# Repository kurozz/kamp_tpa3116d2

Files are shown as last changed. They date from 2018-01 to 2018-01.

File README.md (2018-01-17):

# KAmp

Audio amplifier based on the evaluation module from Texas Instruments.

It should be able to drive 2 speakers at a max of 50W each or a single speaker at a max of 100W (PBTL). Minimal changes are need to change to PBTL.

Multiple devices can be chained together using the Sync connectors. One device should be made Master while the others should operate as Slave devices.

This is not finished and not tested. Will keep updating if I feel like it.

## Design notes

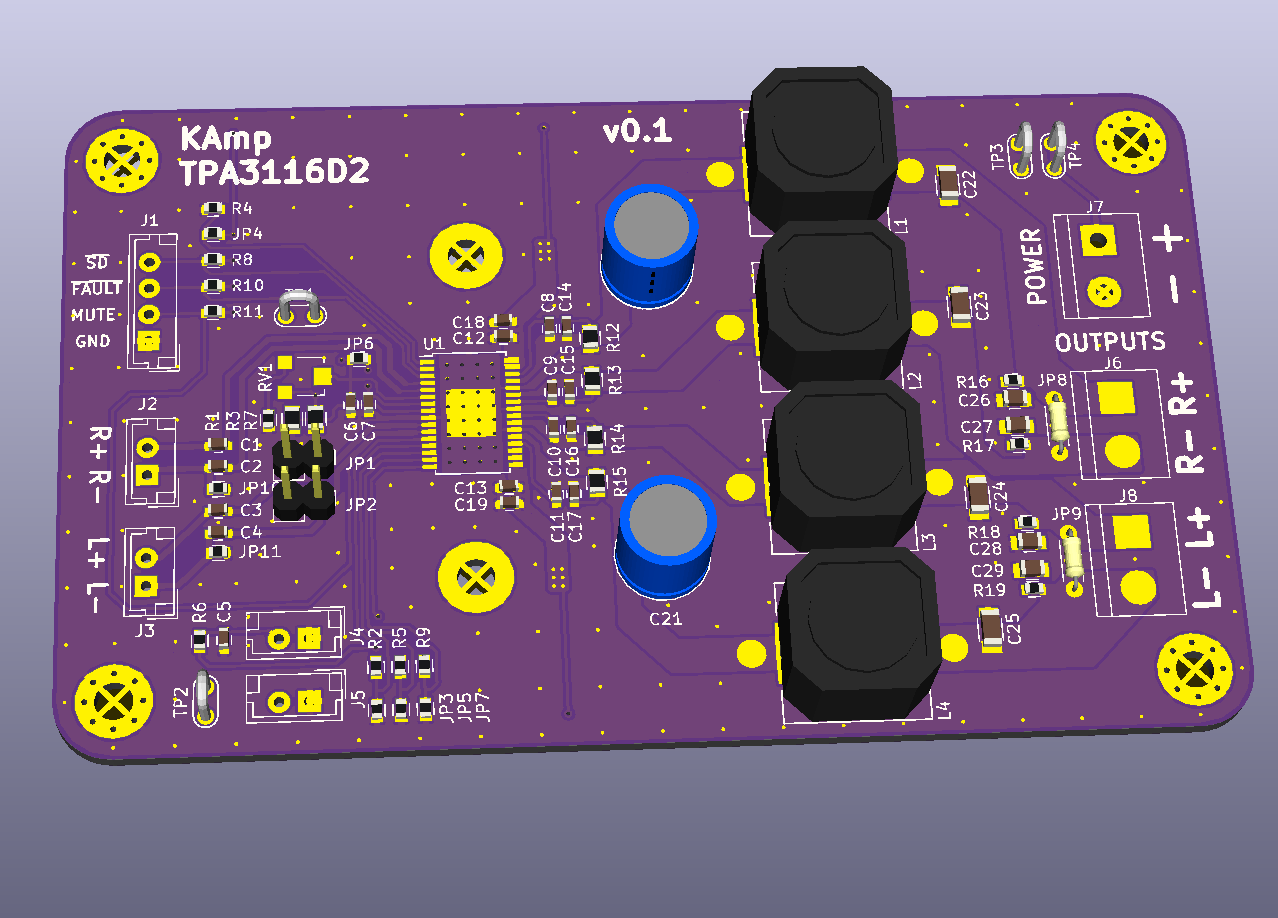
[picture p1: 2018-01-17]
KAmp_TPA3116D2/img/KAmp_TPA3116D2.png

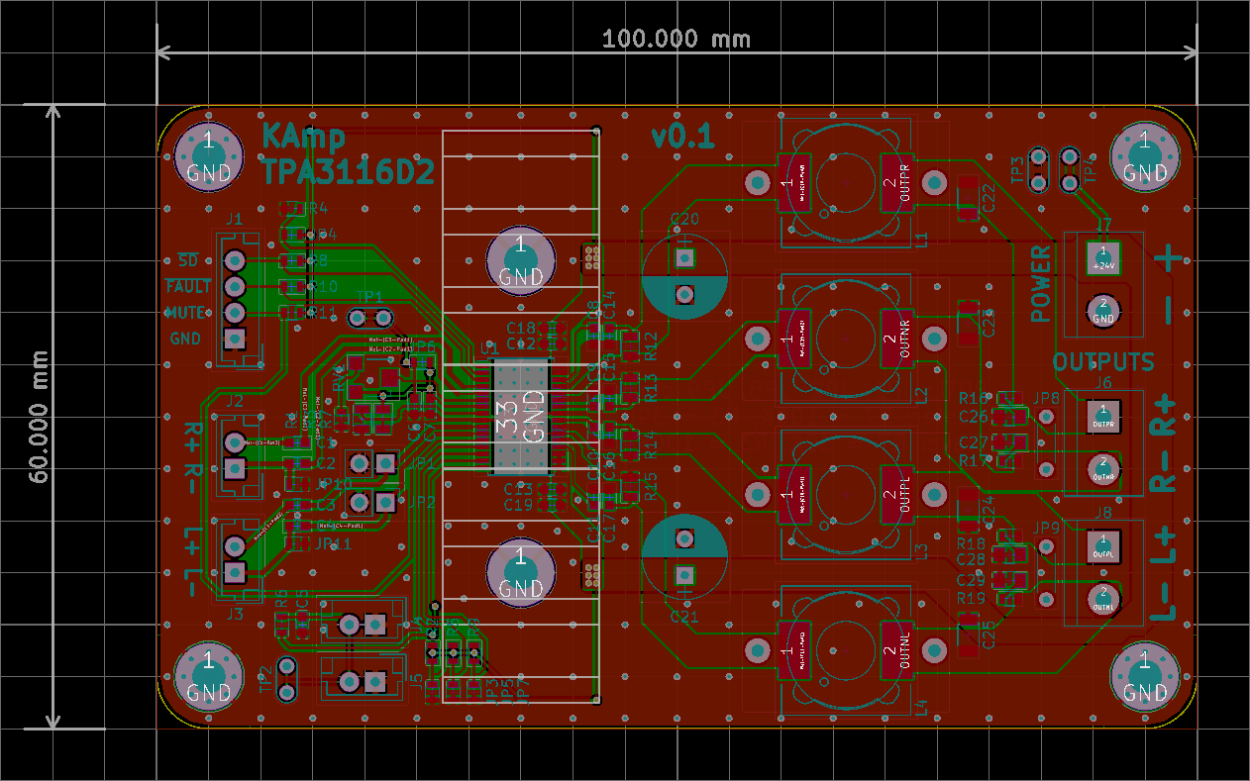
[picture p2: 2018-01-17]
KAmp_TPA3116D2/img/kamp_board.png

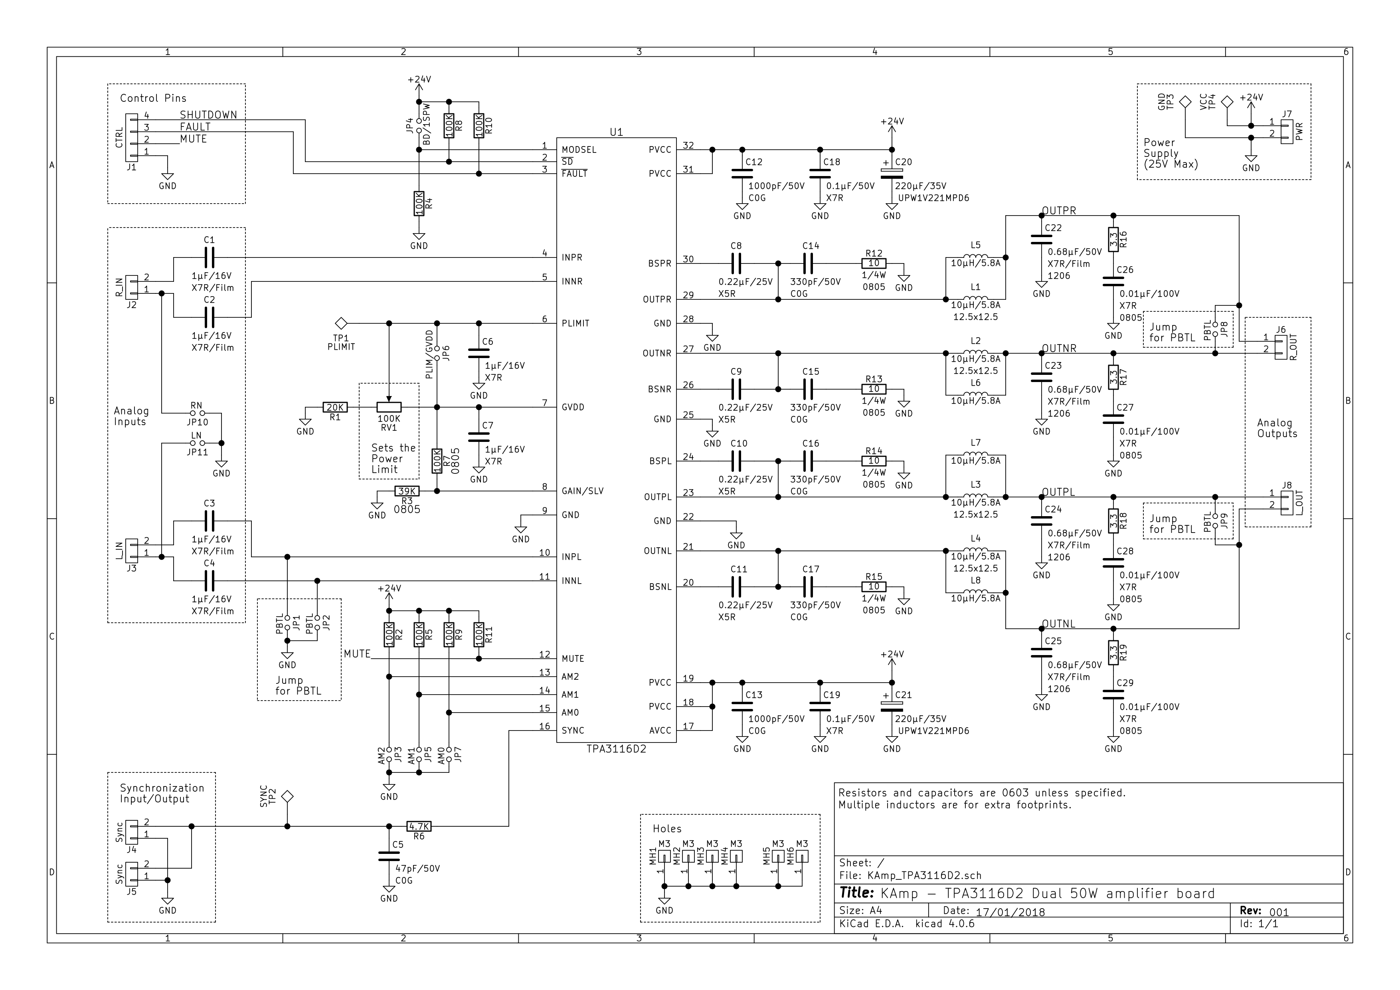
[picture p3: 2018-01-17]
KAmp_TPA3116D2/img/KAmp_TPA3116D2.sch.png

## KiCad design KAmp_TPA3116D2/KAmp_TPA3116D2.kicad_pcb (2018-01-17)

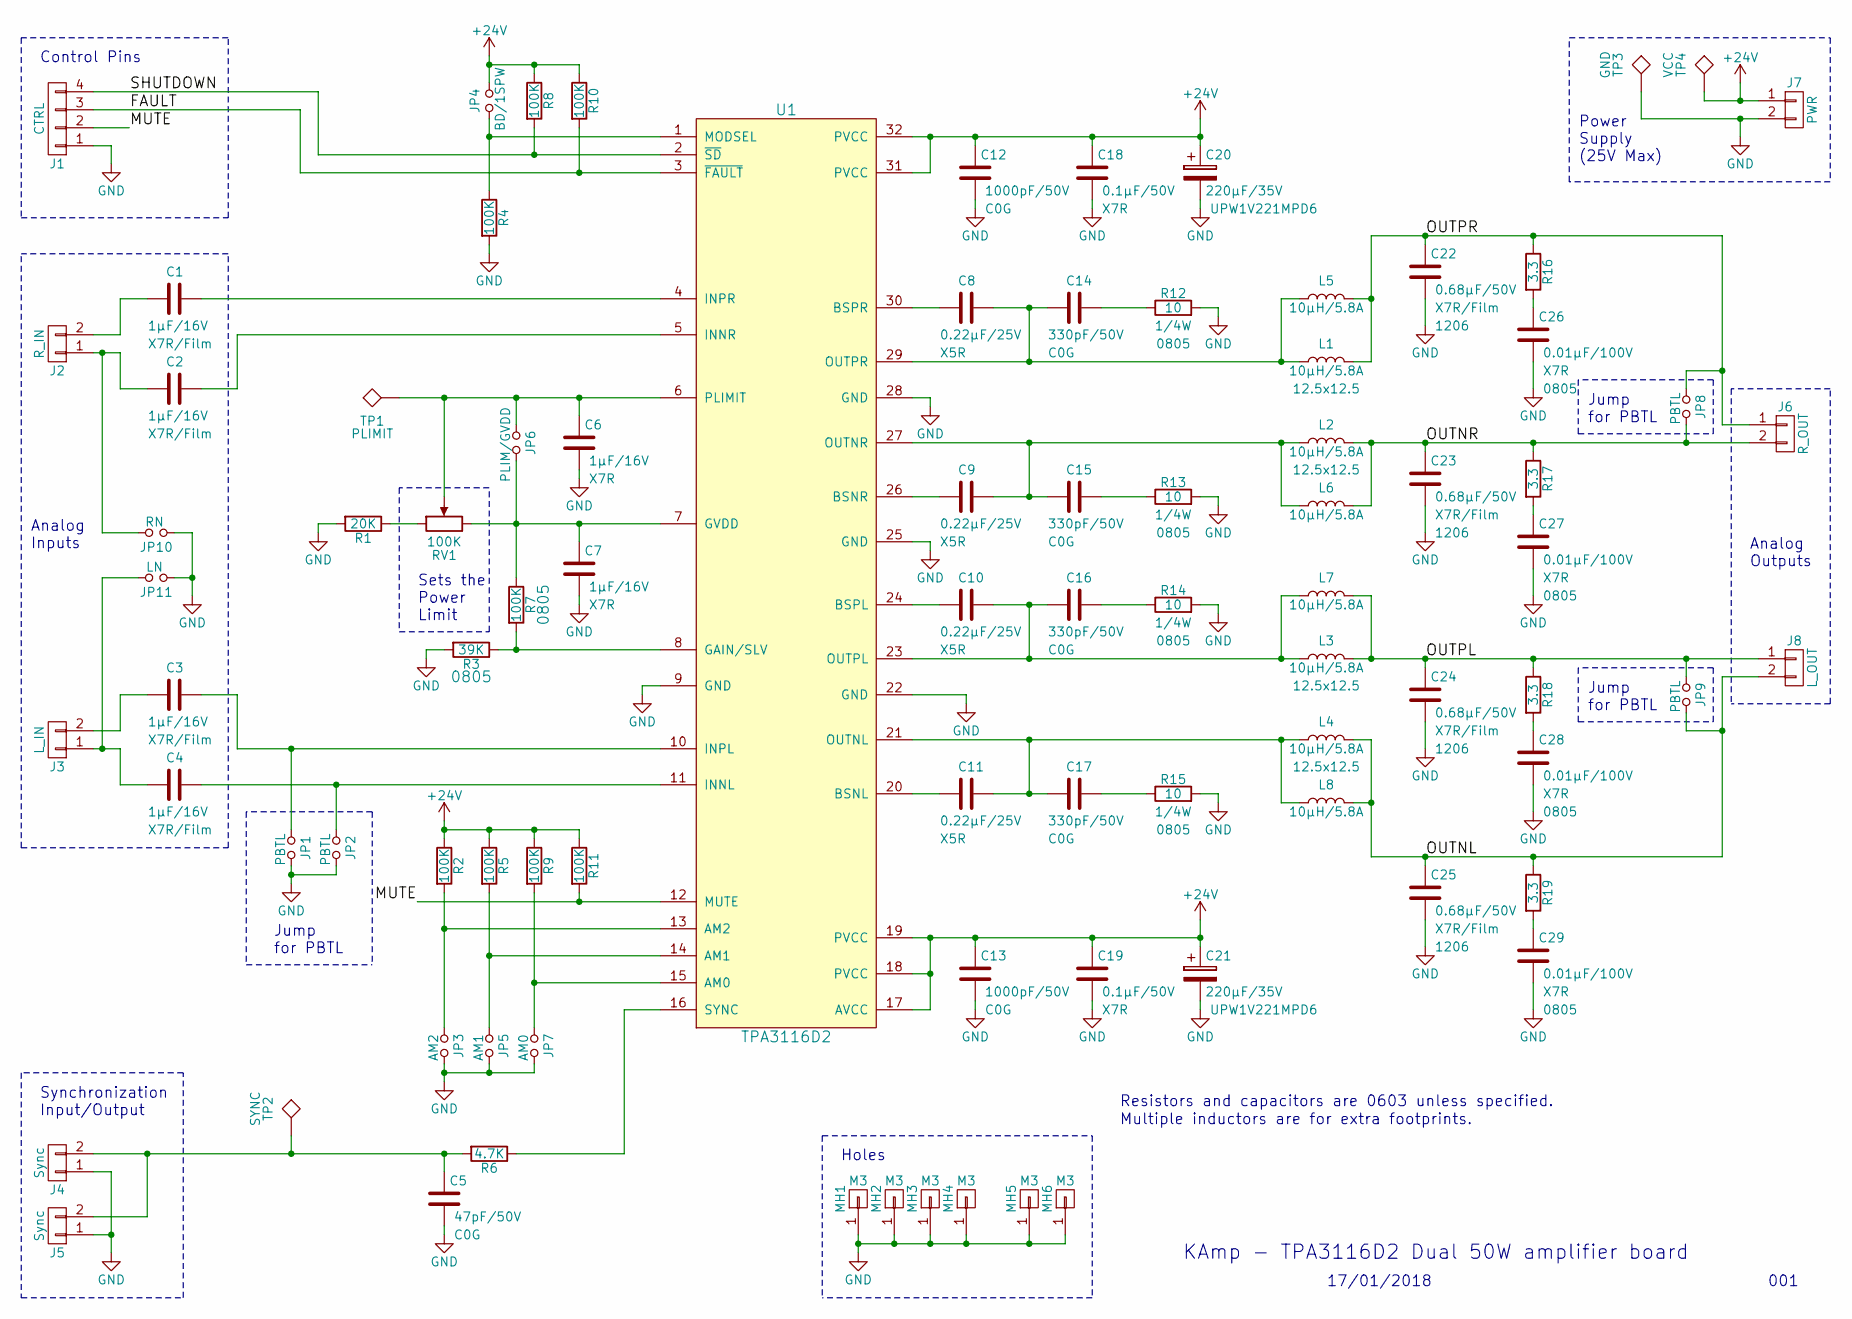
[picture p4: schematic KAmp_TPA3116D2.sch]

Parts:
C1, C2, C3, C4: 1µF/16V; C_0603; Rating X7R/Film
C5: 47pF/50V; C_0603; Rating C0G
C6, C7: 1µF/16V; C_0603; Rating X7R
C8, C9, C10, C11: 0.22µF/25V; C_0603; Rating X5R
C12, C13: 1000pF/50V; C_0603; Rating C0G
C14, C15, C16, C17: 330pF/50V; C_0603; Rating C0G
C18, C19: 0.1µF/50V; C_0603; Rating X7R
C20, C21: 220µF/35V; CP_Radial_D8.0mm_P3.50mm
C22, C23, C24, C25: 0.68µF/50V; C_1206; Rating X7R/Film
C26, C27, C28, C29: 0.01µF/100V; C_0805; Rating X7R
J1: CTRL; JST_EH_B04B-EH-A_04x2.50mm_Straight
J2: R_IN; JST_EH_B02B-EH-A_02x2.50mm_Straight
J3: L_IN; JST_EH_B02B-EH-A_02x2.50mm_Straight
J4, J5: Sync; JST_EH_B02B-EH-A_02x2.50mm_Straight
J6: R_OUT; TerminalBlock_bornier-2_P5.08mm
J7: PWR; TerminalBlock_bornier-2_P5.08mm
J8: L_OUT; TerminalBlock_bornier-2_P5.08mm
JP1, JP2: PBTL; Pin_Header_Straight_1x02_Pitch2.54mm
JP3: AM2; R_0603
JP4: BD/1SPW; R_0603
JP5: AM1; R_0603
JP6: PLIM/GVDD; R_0603
JP7: AM0; R_0603
JP8, JP9: PBTL; R_Axial_DIN0204_L3.6mm_D1.6mm_P5.08mm_Horizontal
JP10: RN; R_0603
JP11: LN; R_0603
L1, L2, L3, L4: 10µH/5.8A; Choke_SMD_12x12mm_h8mm
L5, L6, L7, L8: 10µH/5.8A; L_Toroid_Horizontal_D11.2mm_P17.00mm_Diameter12-5mm_Amidon-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
MH1, MH2, MH3, MH4: M3; MountingHole_3.2mm_M3_Pad_Via
MH5, MH6: M3; MountingHole_3.2mm_M3_Pad
R1: 20K; R_0603
R2, R4, R5, R8, R9, R10, R11: 100K; R_0603
R3: 39K; R_0805
R6: 4.7K; R_0603
R7: 100K; R_0805
R12, R13, R14, R15: 10; R_0805
R16, R17, R18, R19: 3.3; R_0603
RV1: 100K; Potentiometer_Trimmer-EVM3E
TP1: PLIMIT; Test_Point
TP2: SYNC; Test_Point
TP3: GND; Test_Point
TP4: VCC; Test_Point
U1: TPA3116D2; HTSSOP-32_6.1x11mm_Pitch0.65mm_ThermalPad

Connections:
+24V: C12.1, C13.1, C18.1, C19.1, C20.1, C21.1, J7.1, JP4.2, R2.1, R5.1, R8.1, R9.1, R10.1, R11.1, TP4.1, U1.17 (AVCC), U1.18 (PVCC), U1.19 (PVCC), U1.31 (PVCC), U1.32 (PVCC)
/FAULT: J1.3, R10.2, U1.3 (~FAULT)
/MUTE: J1.2, R11.2, U1.12 (MUTE)
/OUTNL: C25.1, J8.2, JP9.2, L4.2, L8.2, R19.1
/OUTNR: C23.1, J6.2, JP8.2, L2.2, L6.2, R17.1
/OUTPL: C24.1, J8.1, JP9.1, L3.2, L7.2, R18.1
/OUTPR: C22.1, J6.1, JP8.1, L1.2, L5.2, R16.1
/SHUTDOWN: J1.4, R8.2, U1.2 (~SD)
GND: C5.2, C6.2, C7.2, C12.2, C13.2, C18.2, C19.2, C20.2, C21.2, C22.2, C23.2, C24.2, C25.2, C26.2, C27.2, C28.2, C29.2, J1.1, J4.1, J5.1, J7.2, JP1.2, JP2.2, JP3.2, JP5.2, JP7.2, JP10.1, JP11.1, MH1.1, MH2.1, MH3.1, MH4.1, MH5.1, MH6.1, R1.2, R3.2, R4.2, R12.2, R13.2, R14.2, R15.2, TP3.1, U1.9 (GND), U1.22 (GND), U1.25 (GND), U1.28 (GND), U1.33 (GND)
unnamed: C1.1, U1.4 (INPR)
unnamed: C1.2, J2.2
unnamed: C2.1, U1.5 (INNR)
unnamed: C2.2, J2.1, JP10.2
unnamed: C3.1, JP1.1, U1.10 (INPL)
unnamed: C3.2, J3.2
unnamed: C4.1, JP2.1, U1.11 (INNL)
unnamed: C4.2, J3.1, JP11.2
unnamed: C5.1, J4.2, J5.2, R6.2, TP2.1
unnamed: C6.1, JP6.1, RV1.2, TP1.1, U1.6 (PLIMIT)
unnamed: C7.1, JP6.2, R7.1, RV1.3, U1.7 (GVDD)
unnamed: C8.2, U1.30 (BSPR)
unnamed: C9.2, U1.26 (BSNR)
unnamed: C10.1, C16.2, L3.1, L7.1, U1.23 (OUTPL)
unnamed: C10.2, U1.24 (BSPL)
unnamed: C11.1, C17.2, L4.1, L8.1, U1.21 (OUTNL)
unnamed: C11.2, U1.20 (BSNL)
unnamed: C14.1, R12.1
unnamed: C8.1, C14.2, L1.1, L5.1, U1.29 (OUTPR)
unnamed: C15.1, R13.1
unnamed: C9.1, C15.2, L2.1, L6.1, U1.27 (OUTNR)
unnamed: C16.1, R14.1
unnamed: C17.1, R15.1
unnamed: C26.1, R16.2
unnamed: C27.1, R17.2
unnamed: C28.1, R18.2
unnamed: C29.1, R19.2
unnamed: JP3.1, R2.2, U1.13 (AM2)
unnamed: JP4.1, R4.1, U1.1 (MODSEL)
unnamed: JP5.1, R5.2, U1.14 (AM1)
unnamed: JP7.1, R9.2, U1.15 (AM0)
unnamed: R1.1, RV1.1
unnamed: R3.1, R7.2, U1.8 (GAIN/SLV)
unnamed: R6.1, U1.16 (SYNC)

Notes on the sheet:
Synchronization Input/Output
Analog Inputs
Jump for PBTL
Control Pins
Power Supply (25V Max)
Analog Outputs
Sets the Power Limit
Holes
KAmp - TPA3116D2 Dual 50W amplifier board
17/01/2018
001
Resistors and capacitors are 0603 unless specified.
Multiple inductors are for extra footprints.

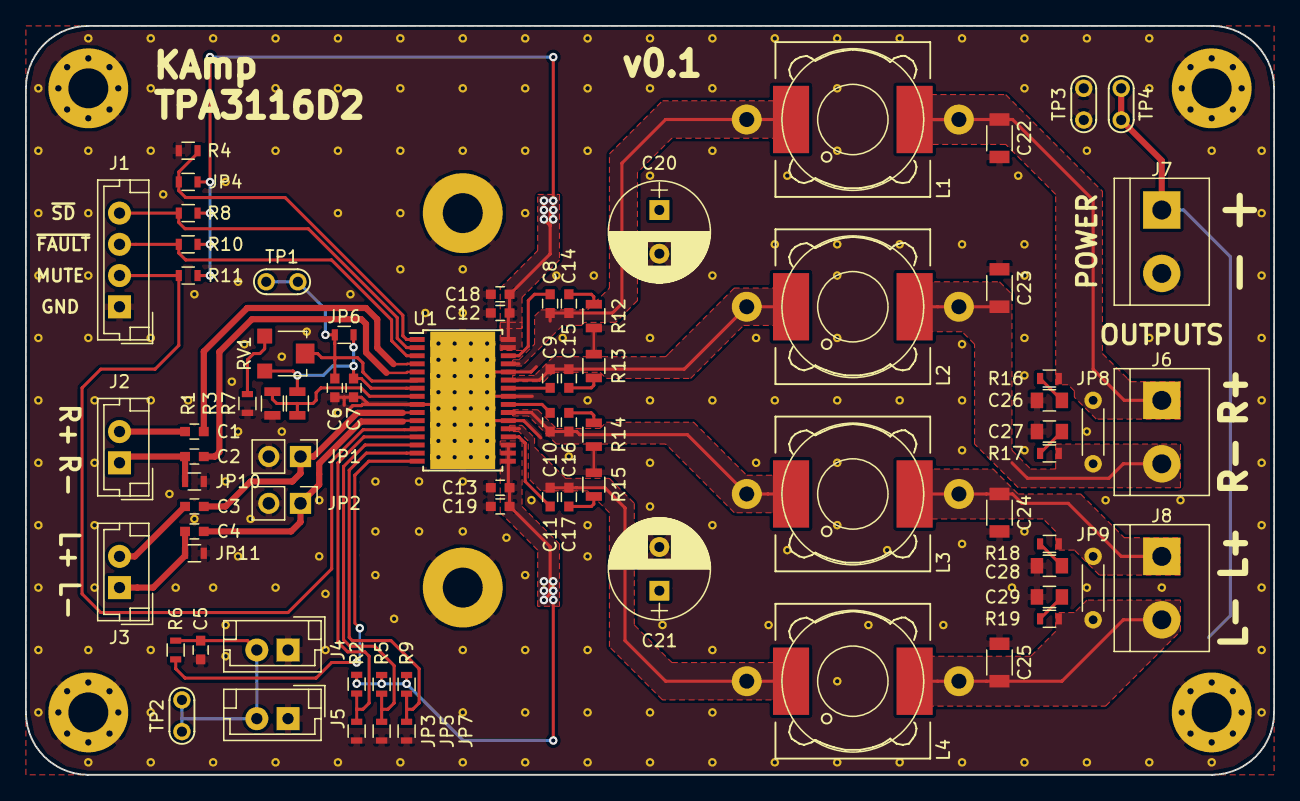
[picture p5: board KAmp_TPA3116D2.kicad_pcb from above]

Board: 2 copper layers, 100.0 x 60.0 mm, 87 parts (0 on the bottom side), 43 nets.
